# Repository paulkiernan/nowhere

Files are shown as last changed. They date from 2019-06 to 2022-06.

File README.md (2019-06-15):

# NowHere

> The difference between nowhere and now here is a little space

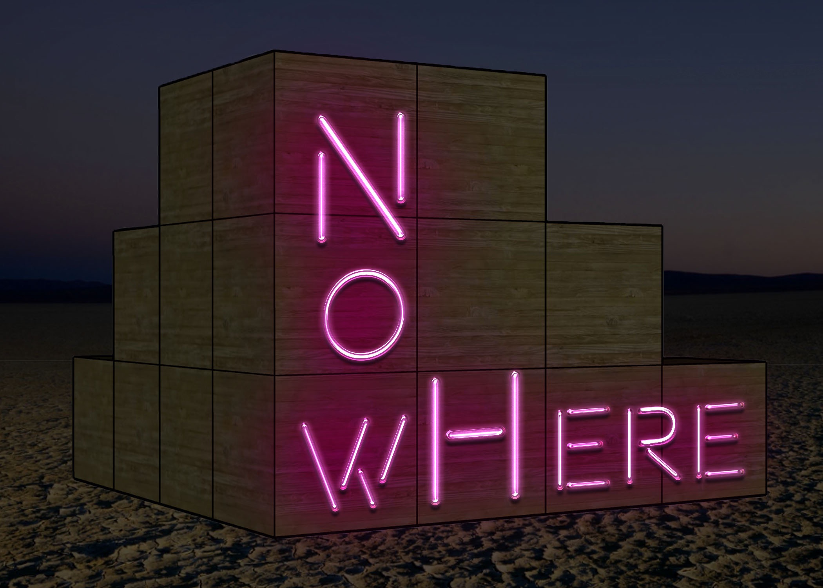
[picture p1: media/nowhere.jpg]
NowHere


[Indiegogo Campaign](https://www.indiegogo.com/projects/nowhere-burning-man-2019#/)

## Development

We use Docker to standardize our build environment. This minimizes uncertainty
around cross-complilation by giving us identical base environments and also
keeps out host environments clean. Currently (2019-06-13) we build for the
Ubuntu Bionic (LTS) target via the DockerFile in the root of this repo.

### Mac Setup

The Teensy loader runs in a X11 window so we need to install XQuartz for flashing
to work on Mac.

```
brew cask install docker
```

* Activate the option ‘Allow connections from network clients’ in XQuartz settings
* Quit & restart XQuartz (to activate the setting)

### Linux Setup

Ubuntu and other modern Linux distibutions use udev to manage device files when
USB devices are added and removed. By default, udev will create a device with
read-only permission which will not allow to you download code. You must place
the udev rules file at /etc/udev/rules.d/49-teensy.rules

```
curl -L https://www.pjrc.com/teensy/49-teensy.rules > /etc/udev/rules.d/49-teensy.rules
```

```bash
./develop
make
make upload
```

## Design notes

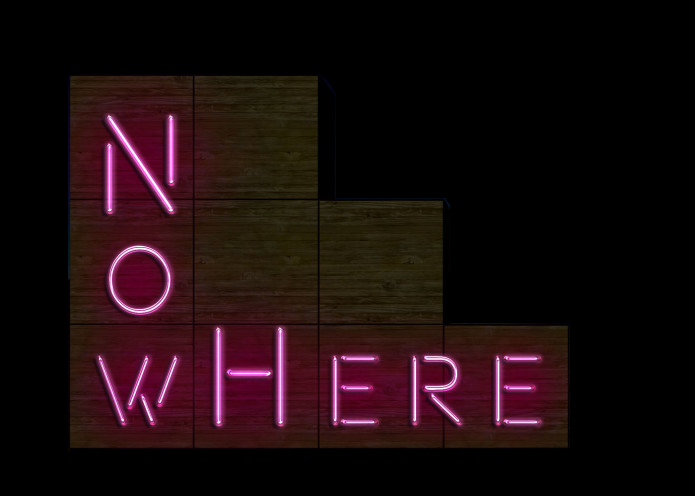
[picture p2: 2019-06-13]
media/nowhere-side.bmp

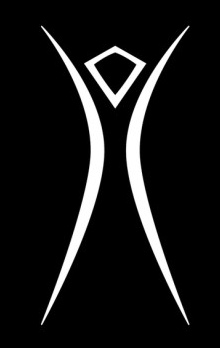
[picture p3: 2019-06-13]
media/the-man.bmp

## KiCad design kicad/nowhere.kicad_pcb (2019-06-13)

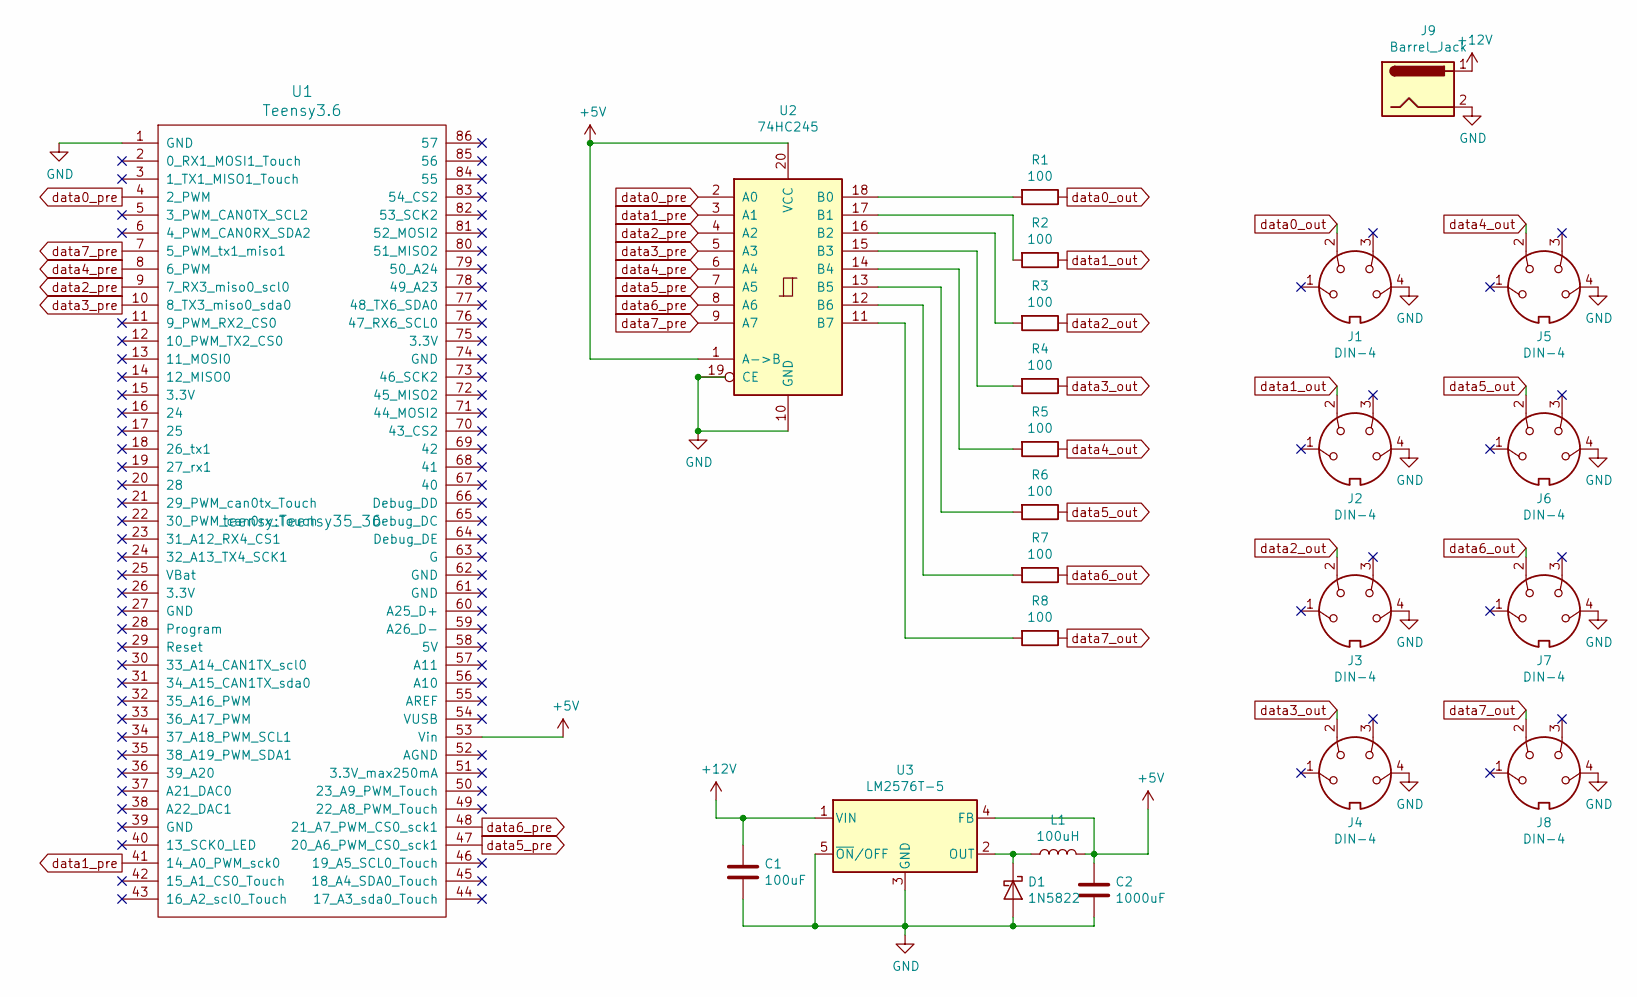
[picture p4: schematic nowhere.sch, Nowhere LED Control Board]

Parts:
C1: 100uF; CP_Radial_D8.0mm_P3.50mm
C2: 1000uF; CP_Radial_D12.5mm_P5.00mm
D1: 1N5822; D_DO-201AD_P15.24mm_Horizontal
J1, J2, J3, J4, J5, J6, J7, J8: DIN-4; Molex_Nano-Fit_105310-xx04_2x02_P2.50mm_Vertical
J9: Barrel_Jack; BarrelJack_CUI_PJ-063AH_Horizontal
L1: 100uH; L_Radial_D12.0mm_P6.00mm_MuRATA_1900R
R1, R2, R3, R4, R5, R6, R7, R8: 100; R_Axial_DIN0207_L6.3mm_D2.5mm_P10.16mm_Horizontal
U1: Teensy3.6; Teensy35_36
U2: 74HC245; DIP-20_W7.62mm
U3: LM2576T-5; TO-220-5_Vertical

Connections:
+5V: C2.1, L1.2, U1.53 (Vin), U2.1 (A->B), U2.20 (VCC), U3.4 (FB)
+12V: C1.1, J9.1, U3.1 (VIN)
GND: C1.2, C2.2, D1.2 (A), J1.4, J2.4, J3.4, J4.4, J5.4, J6.4, J7.4, J8.4, J9.2, U1.1 (GND), U2.10 (GND), U2.19 (CE), U3.3 (GND), U3.5 (~ON~/OFF)
unnamed: D1.1 (K), L1.1, U3.2 (OUT)
unnamed: R1.2, U2.18 (B0)
unnamed: R2.2, U2.17 (B1)
unnamed: R3.2, U2.16 (B2)
unnamed: R4.2, U2.15 (B3)
unnamed: R5.2, U2.14 (B4)
unnamed: R6.2, U2.13 (B5)
unnamed: R7.2, U2.12 (B6)
unnamed: R8.2, U2.11 (B7)
data0_out: J1.2, R1.1
data0_pre: U1.4 (2_PWM), U2.2 (A0)
data1_out: J2.2, R2.1
data1_pre: U1.41 (14_A0_PWM_sck0), U2.3 (A1)
data2_out: J3.2, R3.1
data2_pre: U1.9 (7_RX3_miso0_scl0), U2.4 (A2)
data3_out: J4.2, R4.1
data3_pre: U1.10 (8_TX3_miso0_sda0), U2.5 (A3)
data4_out: J5.2, R5.1
data4_pre: U1.8 (6_PWM), U2.6 (A4)
data5_out: J6.2, R6.1
data5_pre: U1.47 (20_A6_PWM_CS0_sck1), U2.7 (A5)
data6_out: J7.2, R7.1
data6_pre: U1.48 (21_A7_PWM_CS0_sck1), U2.8 (A6)
data7_out: J8.2, R8.1
data7_pre: U1.7 (5_PWM_tx1_miso1), U2.9 (A7)

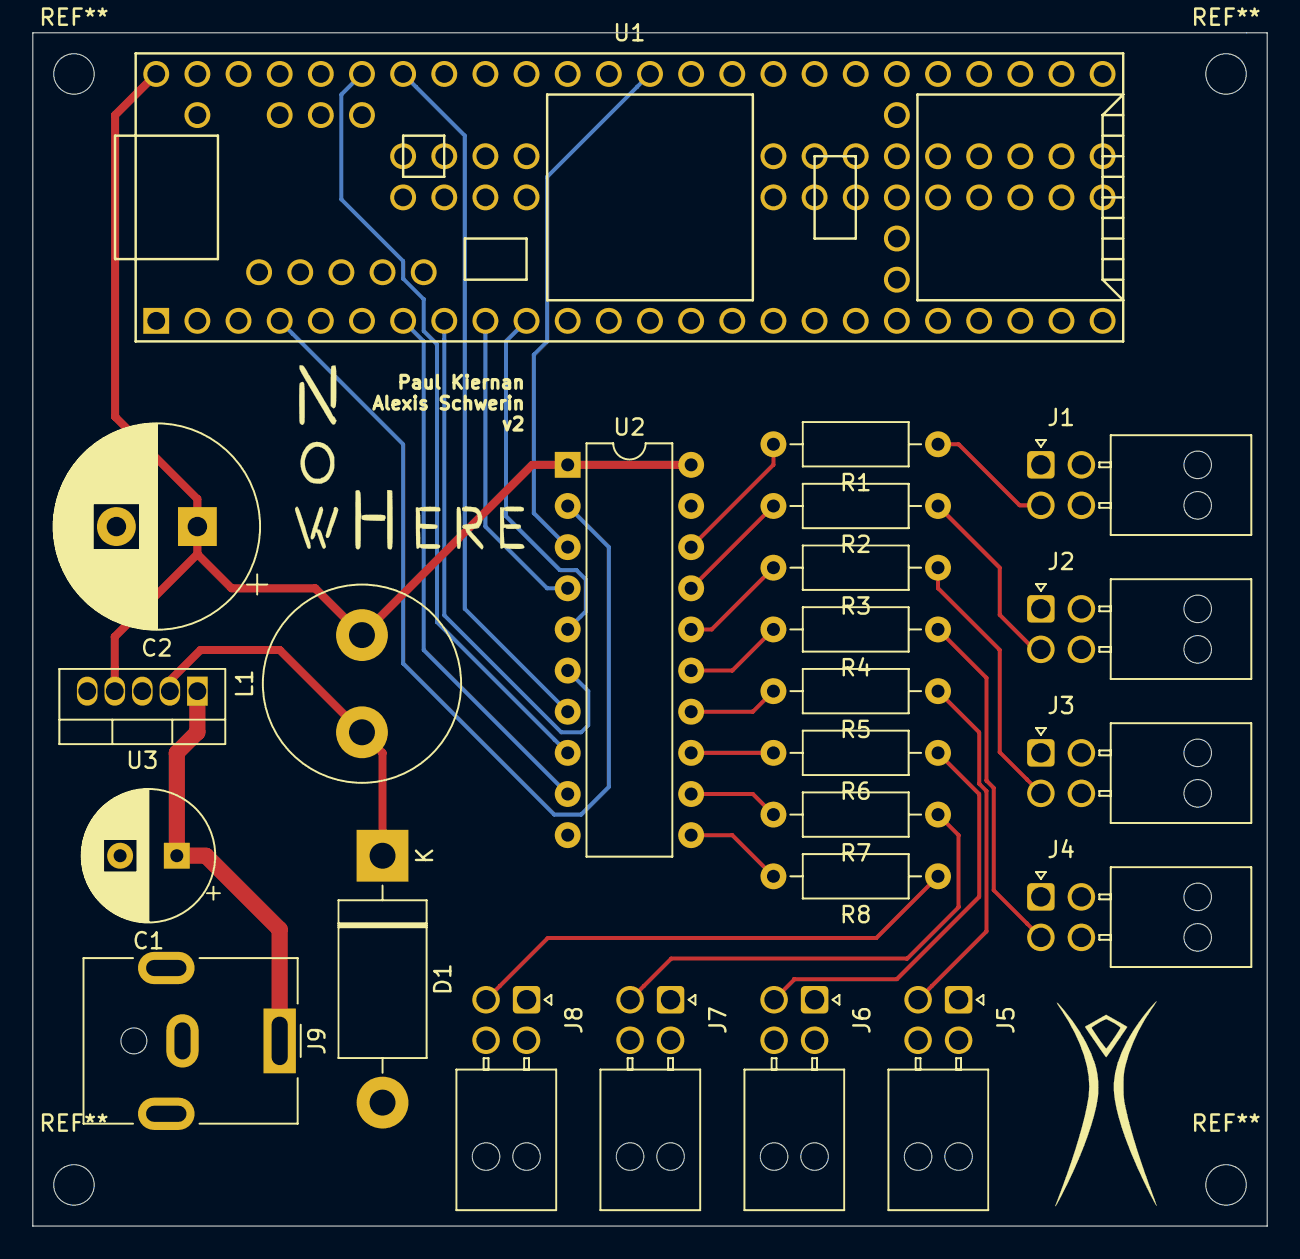
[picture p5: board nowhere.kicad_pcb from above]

Board: 2 copper layers, 76.2 x 73.7 mm, 24 parts (0 on the bottom side), 28 nets.

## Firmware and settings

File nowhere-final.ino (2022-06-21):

#include "FastLED.h"

// How many leds in your strip?
#define NUM_LEDS 300
#define MAX_BRIGHTNESS 50
#define STEP_BRIGHTNESS 128

#define LED_STRIP_N 2
#define LED_STRIP_O 14
#define LED_STRIP_W 7
#define LED_STRIP_H 8
#define LED_STRIP_E1 6
#define LED_STRIP_R 20
#define LED_STRIP_E2 21
#define LED_STRIP_AUX 5

#define LED_PIN 13
#define CHIPSET        WS2813
#define COLOR_ORDER    GRB

int period = 1000;

// Define the array of leds
CRGB led_strip_N[NUM_LEDS];
CRGB led_strip_O[NUM_LEDS];
CRGB led_strip_W[NUM_LEDS];
CRGB led_strip_H[NUM_LEDS];
CRGB led_strip_E1[NUM_LEDS];
CRGB led_strip_R[NUM_LEDS];
CRGB led_strip_E2[NUM_LEDS];
CRGB led_strip_AUX[NUM_LEDS];

int ledStripSize = 7;
CRGB* ledStrips[] = {
    led_strip_N,
    led_strip_O,
    led_strip_W,
    led_strip_H,
    led_strip_E1,
    led_strip_R,
    led_strip_E2
};

int colors[] = {
  CRGB::Amethyst,
  CRGB::Brown,
  CRGB::Chartreuse,
  CRGB::Coral,
  CRGB::Crimson,
  CRGB::DarkBlue,
  CRGB::DarkCyan,
  CRGB::DarkGoldenrod,
  CRGB::DarkGreen,
  CRGB::DarkMagenta,
  CRGB::DarkOrange,
  CRGB::DarkOrchid,
  CRGB::DarkRed,
  CRGB::DarkSlateBlue,
  CRGB::FireBrick,
  CRGB::FloralWhite,
  CRGB::Gold,
  CRGB::Goldenrod,
  CRGB::HotPink,
  CRGB::IndianRed,
  CRGB::Indigo,
  CRGB::Lavender,
  CRGB::LavenderBlush,
  CRGB::LightBlue,
  CRGB::LightCoral,
  CRGB::LightSalmon,
  CRGB::LightSeaGreen,
  CRGB::Maroon,
  CRGB::MediumOrchid,
  CRGB::MediumPurple,
  CRGB::MediumVioletRed,
  CRGB::MistyRose,
  CRGB::Olive,
  CRGB::Plum,
  CRGB::LightGoldenrodYellow
};
int colorArraySize = sizeof(colors) / sizeof(int);

void flicker(int start_index, int end_index, CRGB* leds)
{
    int original_colour_r = leds[start_index].r;
    int original_colour_g = leds[start_index].g;
    int original_colour_b = leds[start_index].b;
    
    int number_flickers = random(1, 5);

    for (int i=0; i < number_flickers; i++) {

        // Turn off
        for (int j=start_index; j < end_index; j++) {
            leds[j] = 0x000000;
        }
        FastLED.show();
        int delay_ms = random(50, 100);
        delay(delay_ms);

        // Turn back on
        for (int j=start_index; j < end_index; j++) {
            leds[j].setRGB(
                original_colour_r,
                original_colour_g,
                original_colour_b
            );
        }
        FastLED.show();
    }
}

void setup() {
  pinMode(LED_PIN, OUTPUT);
  pinMode(LED_STRIP_N, OUTPUT);
  pinMode(LED_STRIP_O, OUTPUT);
  pinMode(LED_STRIP_W, OUTPUT);
  pinMode(LED_STRIP_H, OUTPUT);
  pinMode(LED_STRIP_E1, OUTPUT);
  pinMode(LED_STRIP_R, OUTPUT);
  pinMode(LED_STRIP_E2, OUTPUT);
  pinMode(LED_STRIP_AUX, OUTPUT);
  FastLED.addLeds<CHIPSET, LED_STRIP_N, COLOR_ORDER>(
          led_strip_N,
          NUM_LEDS
  ).setCorrection(TypicalSMD5050);
  FastLED.addLeds<CHIPSET, LED_STRIP_O, COLOR_ORDER>(
          led_strip_O,
          NUM_LEDS
  ).setCorrection(TypicalSMD5050);
  FastLED.addLeds<CHIPSET, LED_STRIP_W, COLOR_ORDER>(
          led_strip_W,
          NUM_LEDS
  ).setCorrection(TypicalSMD5050);
  FastLED.addLeds<CHIPSET, LED_STRIP_H, COLOR_ORDER>(
          led_strip_H,
          NUM_LEDS
  ).setCorrection(TypicalSMD5050);
  FastLED.addLeds<CHIPSET, LED_STRIP_E1, COLOR_ORDER>(
          led_strip_E1,
          NUM_LEDS
  ).setCorrection(TypicalSMD5050);
  FastLED.addLeds<CHIPSET, LED_STRIP_R, COLOR_ORDER>(
          led_strip_R,
          NUM_LEDS
  ).setCorrection(TypicalSMD5050);
  FastLED.addLeds<CHIPSET, LED_STRIP_E2, COLOR_ORDER>(
          led_strip_E2,
          NUM_LEDS
  ).setCorrection(TypicalSMD5050);
  FastLED.addLeds<CHIPSET, LED_STRIP_AUX, COLOR_ORDER>(
          led_strip_AUX,
          NUM_LEDS
  ).setCorrection(TypicalSMD5050);

  // Initialize with color
  int newColor = random (0, colorArraySize);
  for (int strip = 0; strip < ledStripSize; strip++){
      for(int dot = 0; dot < NUM_LEDS; dot++) { 
        led_strip_N[dot] = colors[newColor];
        led_strip_O[dot] = colors[newColor];
        led_strip_W[dot] = colors[newColor];
        led_strip_H[dot] = colors[newColor];
        led_strip_E1[dot] = colors[newColor];
        led_strip_R[dot] = colors[newColor];
        led_strip_E2[dot] = colors[newColor];
        // Strip lighting
        //led_strip_AUX[dot] = CRGB::DarkGoldenrod;
        led_strip_AUX[dot] = 0x777700;
      }
      FastLED.setBrightness(MAX_BRIGHTNESS);
  }
  FastLED.show();
}

void setNewColor()
{
  int newColor = random (0, colorArraySize);
  for(int dot = 0; dot < NUM_LEDS; dot++) { 
      led_strip_N[dot] = colors[newColor];
      led_strip_O[dot] = colors[newColor];
      led_strip_W[dot] = colors[newColor];
      led_strip_H[dot] = colors[newColor];
      led_strip_E1[dot] = colors[newColor];
      led_strip_R[dot] = colors[newColor];
      led_strip_E2[dot] = colors[newColor];
  }
  FastLED.show();
}

void loop() {
    digitalWrite(LED_PIN, HIGH);   // set the LED on
    delay(period);                  // wait for a second
    digitalWrite(LED_PIN, LOW);    // set the LED off
    long random_100 = random(100);
    if(random_100 <= 20){
        int random_led_strip = random(7);
        flicker(0, NUM_LEDS, ledStrips[random_led_strip]);
        long random_color_100 = random(100);
        if(random_color_100 <= 5){
          delay(1000);
          setNewColor();
        }
    } else if (random_100 > 20 && random_100 <= 30) {
        // Flicker W
        flicker(0, NUM_LEDS, led_strip_W);
    } else if (random_100 > 30 && random_100 <= 40) {
        // Flicker H
        flicker(0, NUM_LEDS, led_strip_H);
    }
    delay(period);
}

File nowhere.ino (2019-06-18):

#include <OctoWS2811.h>
#include "logging.h"

#define RED    0xFF0000
#define GREEN  0x00FF00
#define BLUE   0x0000FF
#define YELLOW 0xFFFF00
#define PINK   0xFF1088
#define ORANGE 0xE05800
#define WHITE  0xFFFFFF

const int ledsPerStrip = 300;
int drawingMemory[ledsPerStrip*6];
DMAMEM int displayMemory[ledsPerStrip*6];
OctoWS2811 leds(ledsPerStrip, displayMemory, drawingMemory, WS2811_GRB | WS2811_800kHz);


void flicker(int start_index, int end_index)
{
    int original_colour = leds.getPixel(start_index);
    int number_flickers = random(1, 5);

    for (int i=0; i < number_flickers; i++) {

        // Turn off
        for (int j=start_index; j < end_index; j++) {
            leds.setPixel(j, 0x000000);
        }
        leds.show();
        int delay_ms = random(50, 100);
        delay(delay_ms);

        // Turn back on
        for (int j=start_index; j < end_index; j++) {
            leds.setPixel(j, original_colour);
        }
        leds.show();
    }
}


void setup()
{

    delay(1000);
    Logging::Init();

    leds.begin();

    for (int i=0; i < 150; i++) {
        leds.setPixel(i, RED);
    }

    for (int i=150; i < 300; i++) {
        leds.setPixel(i, GREEN);
    }

    leds.show();

    randomSeed(analogRead(0));
}

void loop()
{
    Logging::log("meow");
    long random_100 = random(100);
    if(random_100 <= 20){
        long red_or_green = random(0, 2);
        if(red_or_green == 0){
            flicker(0, 150);
        } else {
            flicker(150, 300);
        }
    }
    delay(1000);
}

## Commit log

2019-05-31 Init circuit layout
    [nowhere.kicad_pcb, nowhere.sch]
2019-06-06 Add PCB, gerber, and drill files
    [nowhere-B_Cu.gbr, nowhere-B_Mask.gbr, nowhere-B_SilkS.gbr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]
2019-06-13 PCB version 2
    [nowhere-B_Cu.gbr, nowhere-B_Mask.gbr, nowhere-B_SilkS.gbr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]
2019-06-14 Adds docker teensy flash framework
2019-06-14 Fix strip 5 pin
    [nowhere.ino]
